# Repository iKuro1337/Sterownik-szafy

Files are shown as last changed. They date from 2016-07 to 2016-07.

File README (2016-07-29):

Sterownik oświetlenia w szafie oraz przejścia obok szafy

BOM płytka bazowa:
8x rezystor 10k
8x rezystor 60
8x IRLZ44N
8x złącza ARK 2pin
nx Listwy goldpin

BOM płytka sterująca Atmega32:
1x Atmega32
2x Zworka
1x Przycisk monostabilny
1x złącze ARK 2pin
4x kondensator 100n
1x rezystor 10k
1x rezystor pod diode (ok 200)
nx listwy goldpin

BOM obudowa:
3x JACK stereo (2 mogą być MONO)
1x wyświetlacz 4x20 z przetwornikiem i2c
1x czujnik ruchu PIR 5V HC-SR501
WIP czujnik oświetlenia.

Błędy (v1)
1) Odwrócone piny zasilające płytkę bazową 5V i 12V - jest 12V po lewej, 5V po prawej, ma być 5V po lewej, 12 po prawej (płytka Atmega32)
2) Za duży odstęp między pinami 12V,5V i GND wyprowadzonymi na płytce bazowej (płytka bazowa)
3) Za wąskie ścieżki zasilania - należy je pogrubić (wszystko)
4) Pady z przycisku stykają się z ramką płytki (płytka Atmega32)
5) Brak złącza na zasilanie/zasilacz poza obudową (obudowa)
6) Źle podłączane zasilanie - osobna płytka nie ma miejsca do trwałego umiejscowienia.

Podłączenie:
- Wyświetlacz 4x20 podpiąć pod piny 22 i 23 Atmega 32 bezpośrednio. Zasilanie wziąć z wyprowadzeń
- Zworkę podświetlenia wyświetlacza zastąpić przyciskiem kołyskowym bądź innym, spełniającym funkcję włączania/wyłączania podświetlenia.
- Oświetlenie jest podłączane do kolejnych złącz ARK na dowolnej zasadzie.
- Podłączenie czujnika ruchu PIR tylko i wyłącznie na pin 1 - wpinany na pojedyncze gniazdo JACK
- Podłączenie czujników otwarcia/zamknięcia strony szafy podłączyć do pinów 2 i 3, drugą stronę złączyć z masą - wpinane na wybrane jedno z dwóch gniazd JACK
- Poszczególne gniazda mają następujące funkcje (od prawej góry, dołu, do lewej strony dołu)
  1) Światło zewnętrzne zapalające się zawsze jak jest ruch
  2) Światło wewnętrzne szafy, góra, zapalająca się kiedy którekolwiek z drzwi jest otwarte
  3) Światło wewnętrzne szafy, lewa strona, zapalająca się kiedy lewe drzwi są otwarte
  4) Światło wewnętrzne szafy, lewa strona, zapalająca się kiedy lewe drzwi są otwarte
  5) Światło wewnętrzne szafy, prawa strona, zapalająca się kiedy prawe drzwi są otwarte
  6) Światło wewnętrzne szafy, prawa strona, zapalająca się kiedy prawe drzwi są otwarte
  7) Światło wewnętrzne szafy, prawa strona, zapalająca się kiedy prawe drzwi są otwarte
  8) Światło wewnętrzne szafy, prawa strona, zapalająca się kiedy prawe drzwi są otwarte
- Płytkę zasilającą ustawiamy na 5V, przylutowujemy do niej 4 kable (po poprawce) bądź 6 kabli (przed korektą) skręconą parę czerwony/czarny podpinamy od strony zasilania płytki. Dodatkowy przewód od strony +12V podłączany jest po prawej stronie płytki bazowej. przewód czerwony podłączamy po prawej stronie trójki pinów zasilających. przewód czerwony ma być podpięty po lewej stronie płytki.

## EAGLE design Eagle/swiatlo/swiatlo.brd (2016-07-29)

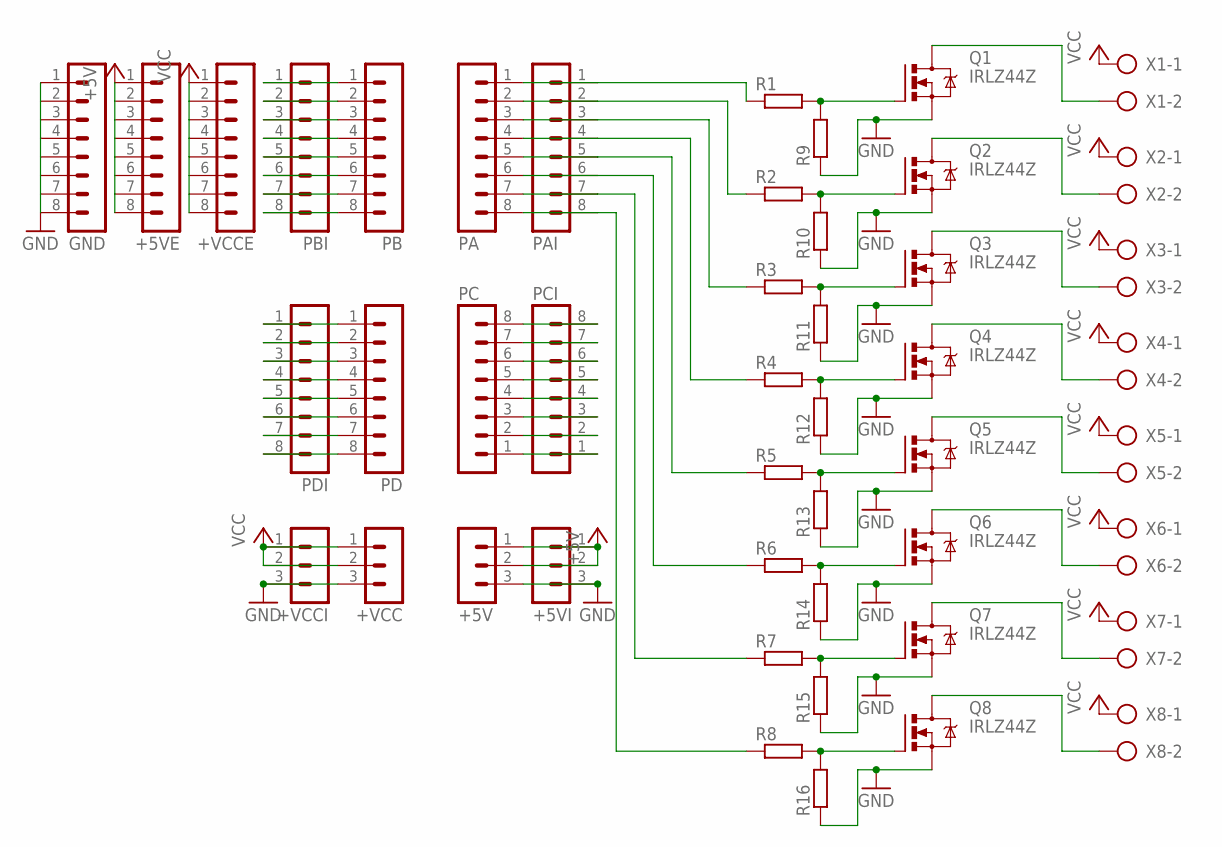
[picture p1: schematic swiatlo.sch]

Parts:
+5V, +5VI: MA03-1
+5VE: MA08-1
+VCC: MA03-1
+VCCE: MA08-1
+VCCI: MA03-1
GND: MA08-1
PA: MA08-1
PAI: MA08-1
PB: MA08-1
PBI: MA08-1
PC: MA08-1
PCI: MA08-1
PD: MA08-1
PDI: MA08-1
Q1, Q2, Q3, Q4, Q5, Q6, Q7, Q8: IRLZ44Z; TO220BH
R1, R2, R3, R4, R5, R6, R7, R8, R9, R10, R11, R12, R13, R14, R15, R16: R-EU_0204/7; 0204/7
X1, X2, X3, X4, X5, X6, X7, X8: AK300/2

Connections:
+5V: +5V.1, +5V.2, +5VE.1, +5VE.2, +5VE.3, +5VE.4, +5VE.5, +5VE.6, +5VE.7, +5VE.8, +5VI.1, +5VI.2
GND: +5V.3, +5VI.3, +VCC.3, +VCCI.3, GND.1, GND.2, GND.3, GND.4, GND.5, GND.6, GND.7, GND.8, Q1.S, Q2.S, Q3.S, Q4.S, Q5.S, Q6.S, Q7.S, Q8.S, R9.1, R10.1, R11.1, R12.1, R13.1, R14.1, R15.1, R16.1
unnamed: Q1.G, R1.2, R9.2
unnamed: Q2.G, R2.2, R10.2
unnamed: Q3.G, R3.2, R11.2
unnamed: Q4.G, R4.2, R12.2
unnamed: Q5.G, R5.2, R13.2
unnamed: Q6.G, R6.2, R14.2
unnamed: Q7.G, R7.2, R15.2
unnamed: Q8.G, R8.2, R16.2
unnamed: Q1.D, X1.2
unnamed: Q2.D, X2.2
unnamed: Q3.D, X3.2
unnamed: Q4.D, X4.2
unnamed: Q5.D, X5.2
unnamed: Q6.D, X6.2
unnamed: Q7.D, X7.2
unnamed: Q8.D, X8.2
unnamed: PC.8, PCI.8
unnamed: PC.7, PCI.7
unnamed: PC.6, PCI.6
unnamed: PC.5, PCI.5
unnamed: PC.4, PCI.4
unnamed: PC.3, PCI.3
unnamed: PC.2, PCI.2
unnamed: PC.1, PCI.1
unnamed: PA.1, PAI.1, R1.1
unnamed: PA.2, PAI.2, R2.1
unnamed: PA.3, PAI.3, R3.1
unnamed: PA.4, PAI.4, R4.1
unnamed: PA.5, PAI.5, R5.1
unnamed: PA.6, PAI.6, R6.1
unnamed: PA.7, PAI.7, R7.1
unnamed: PA.8, PAI.8, R8.1
unnamed: PD.8, PDI.8
unnamed: PD.7, PDI.7
unnamed: PD.6, PDI.6
unnamed: PD.5, PDI.5
unnamed: PD.4, PDI.4
unnamed: PD.3, PDI.3
unnamed: PD.2, PDI.2
unnamed: PD.1, PDI.1
unnamed: PB.8, PBI.8
unnamed: PB.7, PBI.7
unnamed: PB.6, PBI.6
unnamed: PB.5, PBI.5
unnamed: PB.4, PBI.4
unnamed: PB.3, PBI.3
unnamed: PB.2, PBI.2
unnamed: PB.1, PBI.1
VCC: +VCC.1, +VCC.2, +VCCE.1, +VCCE.2, +VCCE.3, +VCCE.4, +VCCE.5, +VCCE.6, +VCCE.7, +VCCE.8, +VCCI.1, +VCCI.2, X1.1, X2.1, X3.1, X4.1, X5.1, X6.1, X7.1, X8.1

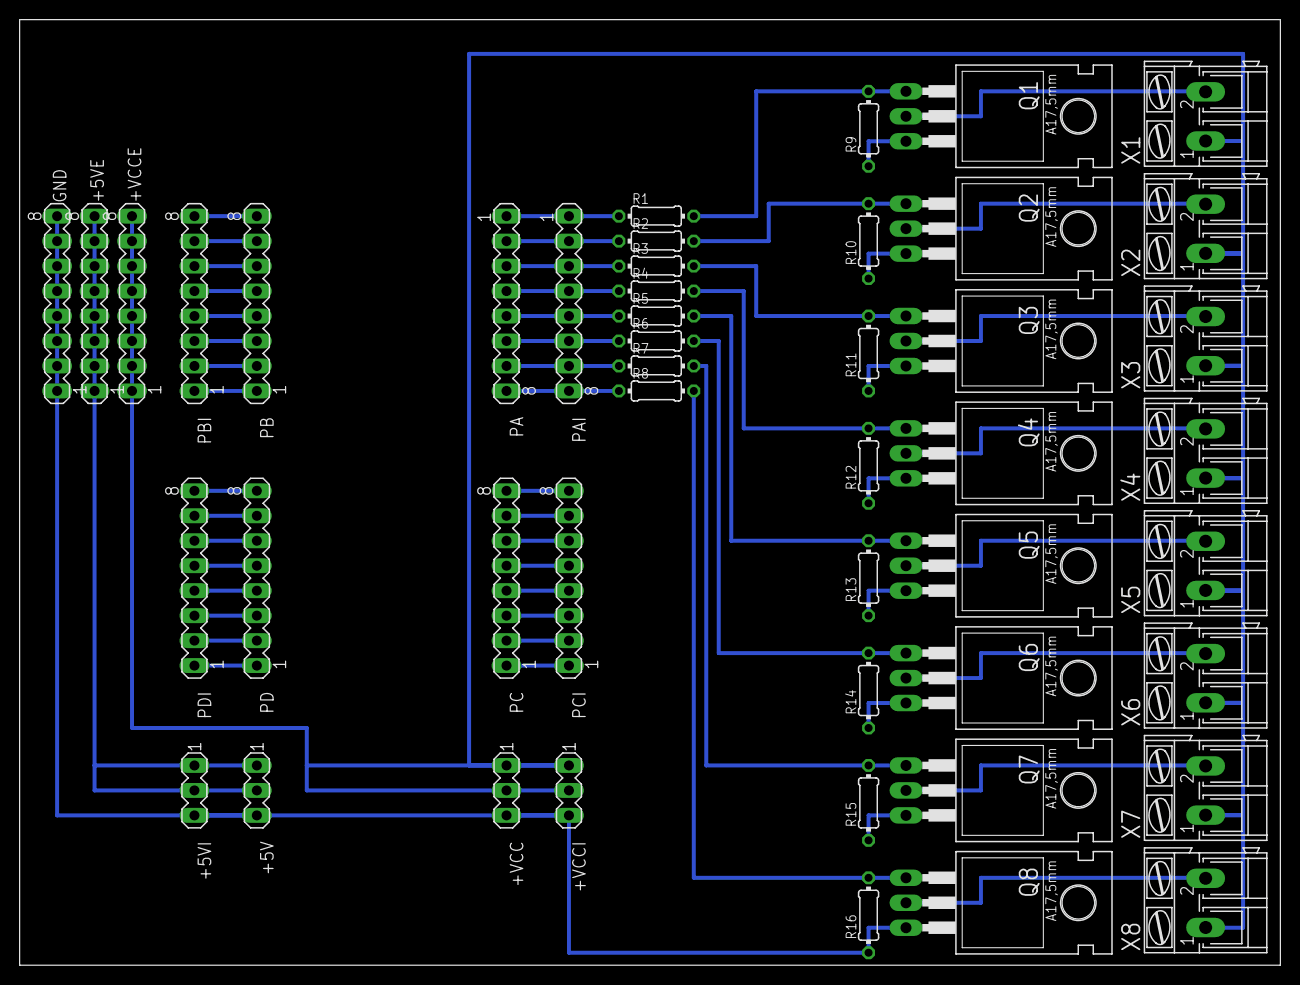
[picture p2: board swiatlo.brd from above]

Board: 2 copper layers, 128.2 x 96.2 mm, 47 parts (0 on the bottom side), 51 nets.

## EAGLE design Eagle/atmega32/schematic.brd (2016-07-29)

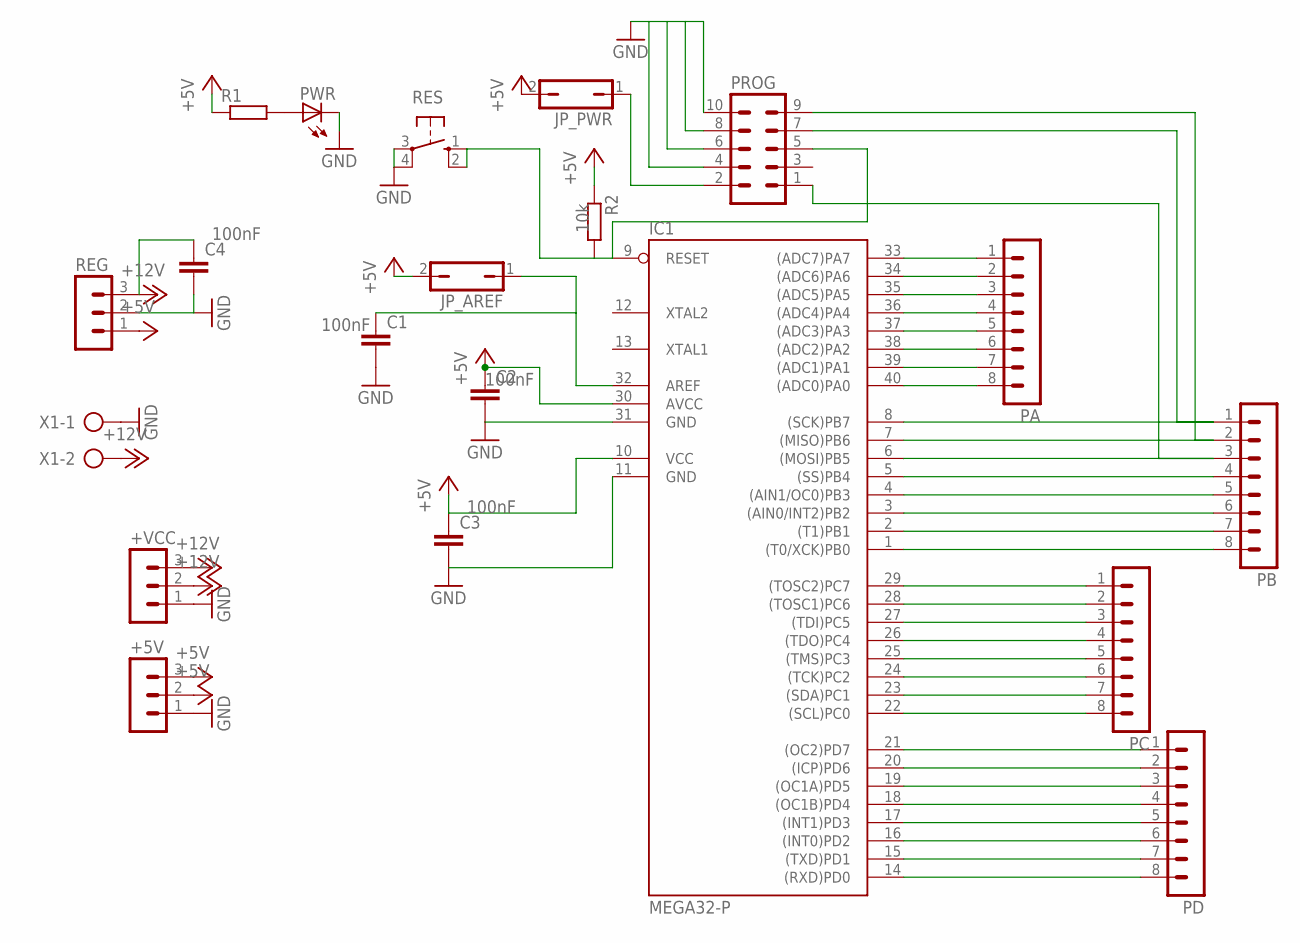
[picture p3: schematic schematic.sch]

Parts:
+5V: MA03-1
+VCC: MA03-1
C1, C2, C3, C4: C2,5-3; C2.5-3
IC1: MEGA32-P; DIL40
JP_AREF: JP1Q; JP1
JP_PWR: JP1Q; JP1
PA: MA08-1
PB: MA08-1
PC: MA08-1
PD: MA08-1
PROG: MA05-2
PWR: LED_E; LED_1206
R1, R2: RR1206; R1206
REG: MA03-1
RES: 10-XX; B3F-10XX
X1: AK300/2

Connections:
+5V: +5V.2, +5V.3, C2.1, C3.1, IC1.10 (VCC), IC1.30 (AVCC), JP_AREF.2, JP_PWR.2, R1.1, R2.1, REG.1
+12V: +VCC.2, +VCC.3, C4.1, REG.3, X1.2
GND: +5V.1, +VCC.1, C1.2, C2.2, C3.2, C4.2, IC1.11 (GND), IC1.31 (GND), PROG.4, PROG.6, PROG.8, PROG.10, PWR.C, REG.2, RES.3, RES.4 (P1), X1.1
unnamed: IC1.21 ((OC2)PD7), PD.1
unnamed: IC1.20 ((ICP)PD6), PD.2
unnamed: IC1.19 ((OC1A)PD5), PD.3
unnamed: IC1.18 ((OC1B)PD4), PD.4
unnamed: IC1.17 ((INT1)PD3), PD.5
unnamed: IC1.16 ((INT0)PD2), PD.6
unnamed: IC1.15 ((TXD)PD1), PD.7
unnamed: IC1.14 ((RXD)PD0), PD.8
unnamed: IC1.29 ((TOSC2)PC7), PC.1
unnamed: IC1.28 ((TOSC1)PC6), PC.2
unnamed: IC1.27 ((TDI)PC5), PC.3
unnamed: IC1.26 ((TDO)PC4), PC.4
unnamed: IC1.25 ((TMS)PC3), PC.5
unnamed: IC1.24 ((TCK)PC2), PC.6
unnamed: IC1.23 ((SDA)PC1), PC.7
unnamed: IC1.22 ((SCL)PC0), PC.8
unnamed: IC1.8 ((SCK)PB7), PB.1, PROG.7
unnamed: IC1.7 ((MISO)PB6), PB.2, PROG.9
unnamed: IC1.6 ((MOSI)PB5), PB.3, PROG.1
unnamed: IC1.5 ((SS)PB4), PB.4
unnamed: IC1.4 ((AIN1/OC0)PB3), PB.5
unnamed: IC1.3 ((AIN0/INT2)PB2), PB.6
unnamed: IC1.2 ((T1)PB1), PB.7
unnamed: IC1.1 ((T0/XCK)PB0), PB.8
unnamed: IC1.33 ((ADC7)PA7), PA.1
unnamed: IC1.34 ((ADC6)PA6), PA.2
unnamed: IC1.35 ((ADC5)PA5), PA.3
unnamed: IC1.36 ((ADC4)PA4), PA.4
unnamed: IC1.37 ((ADC3)PA3), PA.5
unnamed: IC1.38 ((ADC2)PA2), PA.6
unnamed: IC1.39 ((ADC1)PA1), PA.7
unnamed: IC1.40 ((ADC0)PA0), PA.8
unnamed: IC1.9 (RESET), PROG.5, R2.2, RES.1 (S), RES.2 (S1)
unnamed: C1.1, IC1.32 (AREF), JP_AREF.1
unnamed: JP_PWR.1, PROG.2
unnamed: PWR.A, R1.2

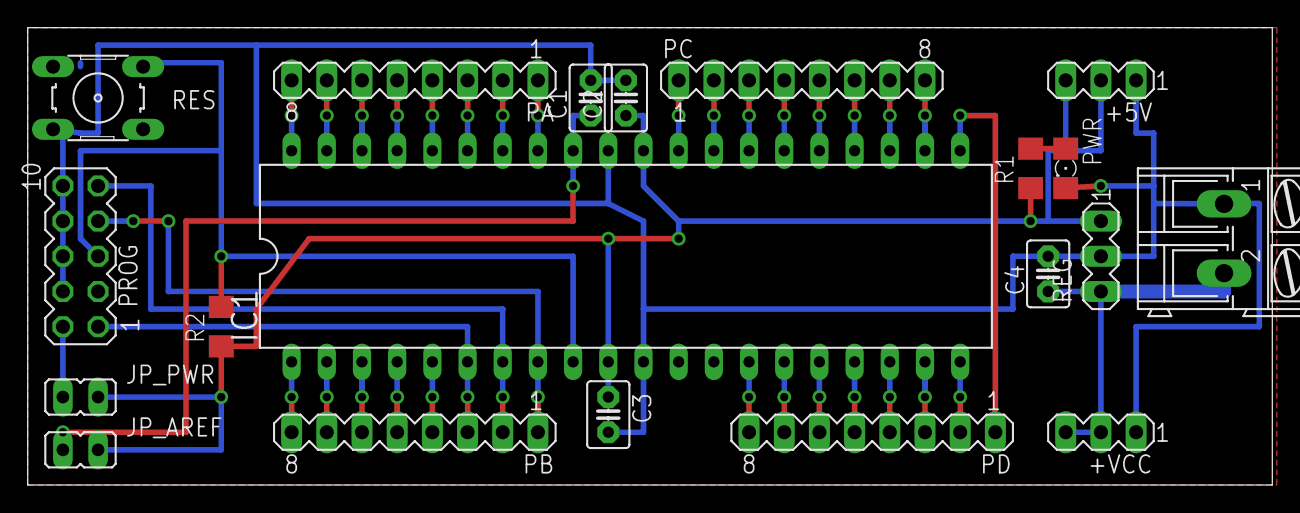
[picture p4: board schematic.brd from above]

Board: 2 copper layers, 89.8 x 33.0 mm, 20 parts (0 on the bottom side), 39 nets.

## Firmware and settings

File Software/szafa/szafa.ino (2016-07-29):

#include <BH1750.h>
#include <Wire.h>
#include <LiquidCrystal_I2C.h>

LiquidCrystal_I2C lcd(0x27, 20,4);  // Ustawienie adresu ukladu na 0x27
//BH1750 czujnikSwiatla;

#define PIRinput 0b00000001 //0
#define czujnikLewy 0b00000010 //1
#define czujnikPrawy 0b00000100 //2
#define prz1 0b00001000 //3
#define prz2 0b00010000 //4
#define prz3 0b00100000 //5
#define prz4 0b01000000 //6
#define debug_on 0b10000000 //7

#define szafaZewnatrz 0b00000001 //31
#define szafaGora 0b00000010 //30
#define szafaPolka1 0b00000100 //29
#define szafaPolka2 0b00001000 //28
#define szafaPolka3 0b00010000 //27
#define szafaPolka4 0b00100000 //26
#define szafaPolka5 0b01000000 //25
#define szafaPolka6 0b10000000 //24

void setup() {
  //BH1750
  //czujnikSwiatla.configure(BH1750_CONTINUOUS_LOW_RES_MODE);

  //LCD
  lcd.init();     // Inicjalizacja LCD 4x20
  lcd.backlight();
  lcd.setCursor(0,0);
  lcd.print("Program: Oswietlenie");
  lcd.setCursor(0,1);
  lcd.print("szafy 2.0");
  delay(500);

  //PINY - INPUT
  //  pinMode(PIRinput, INPUT_PULLUP);
  //  pinMode(czujnikLewy, INPUT_PULLUP);
  //  pinMode(czujnikPrawy, INPUT_PULLUP);
  DDRB |= 0b00000000;
  PORTB |= 0b00000110;

  //PINY - OUTPUT
  //  pinMode(szafaZewnatrz, OUTPUT);
  //  pinMode(szafaGora, OUTPUT);
  //  pinMode(szafaPolka1, OUTPUT);
  //  pinMode(szafaPolka2, OUTPUT);
  //  pinMode(szafaPolka3, OUTPUT);
  //  pinMode(szafaPolka4, OUTPUT);
  //  pinMode(szafaPolka5, OUTPUT);
  //  pinMode(szafaPolka6, OUTPUT);
  DDRA |= 0b11111111;
  PORTA |= 0b00000000;


  for (int i = 0; i < 8; i++) {
    lcd.setCursor(i+6,2);
    lcd.print("*");
    PORTA = (0b00000001 << i);
    delay(1000);
  }
  lcd.clear();
  lcd.setCursor(0,0);

}

void diagnostykaLCD(uint16_t lux_in, bool pir_in, bool czl_in, bool czp_in, bool szZ, bool szG, bool sz1, bool sz2, bool sz3, bool sz4, bool sz5, bool sz6) {
  char buffer[20];

  //lcd.clear();
  //stany wejsc na wyswietlacz
  sprintf(buffer, "PIR %01d CZL %01d CZP %01d   ", pir_in, czl_in, czp_in);
  lcd.setCursor(0,0);
  lcd.print(buffer);

  //stany wyjsc na wyswietlacz
  sprintf(buffer, "SZ %01d SG %01d P1 %01d P2 %01d ", szZ, szG, sz1, sz2);
  lcd.setCursor(0,1);
  lcd.print(buffer);
  sprintf(buffer, "P3 %01d P4 %01d P5 %01d P6 %01d ", sz3, sz4, sz5, sz6);
  lcd.setCursor(0,2);
  lcd.print(buffer);

  //czujnik oswietlenia
  sprintf(buffer, "LUX %05d  ", lux_in);
  lcd.setCursor(0,3);
  lcd.print(buffer);
}

void loop() {
  //********************************************************************************************************************************************************************************
  //DEFINICJE
  //********************************************************************************************************************************************************************************

  byte WEJSCIA = PINB;
  byte WYJSCIA_st = PINA;
  byte WYJSCIA_out = 0b00000000;

  //********************************************************************************************************************************************************************************
  //SPRAWDZANIE STANOW
  //********************************************************************************************************************************************************************************

  //WEJSCIA
  uint16_t lux_st/*=czujnikSwiatla.readLightLevel()*/;
  bool PIR_st = (WEJSCIA & PIRinput); //digitalRead(PIRinput);
  bool CZL_st = (WEJSCIA & czujnikLewy); //digitalRead(czujnikLewy);
  bool CZP_st = (WEJSCIA & czujnikPrawy); //digitalRead(czujnikPrawy);

  //WYJSCIA
  bool SZZ_st = (WYJSCIA_st & szafaZewnatrz); //digitalRead(szafaZewnatrz);
  bool SZG_st = (WYJSCIA_st & szafaGora); //digitalRead(szafaGora);
  bool SZ1_st = (WYJSCIA_st & szafaPolka1); //digitalRead(szafaPolka1);
  bool SZ2_st = (WYJSCIA_st & szafaPolka2); //digitalRead(szafaPolka2);
  bool SZ3_st = (WYJSCIA_st & szafaPolka3); //digitalRead(szafaPolka3);
  bool SZ4_st = (WYJSCIA_st & szafaPolka4); //digitalRead(szafaPolka4);
  bool SZ5_st = (WYJSCIA_st & szafaPolka5); //digitalRead(szafaPolka5);
  bool SZ6_st = (WYJSCIA_st & szafaPolka6); //digitalRead(szafaPolka6);

  //********************************************************************************************************************************************************************************
  //PROGRAM
  //********************************************************************************************************************************************************************************

  //Jezeli wykryto ruch:
  WYJSCIA_out |= PIR_st ? szafaZewnatrz : 0b00000000;
  WYJSCIA_out |= (PIR_st & (CZL_st | CZP_st)) ? szafaGora : 0b00000000;
  WYJSCIA_out |= (PIR_st & CZL_st) ? szafaPolka1 + szafaPolka2 : 0b00000000;
  WYJSCIA_out |= (PIR_st & CZP_st) ? szafaPolka3 + szafaPolka4 + szafaPolka5 + szafaPolka6 : 0b00000000;
  //WYJSCIA_out |= (PIR_st & (CZL_st | CZP_st)) ? (0b11111111) : (0b00000000);
  //PORTA ^= szafaPolka1; //digitalWrite(szafaPolka3,!digitalRead(szafaPolka3));


  //********************************************************************************************************************************************************************************
  //WYSTEROWANIE WYJSC
  //********************************************************************************************************************************************************************************

  PORTA = WYJSCIA_out;
  delay(200);

  //diagnostyka stanów na podpiętym LCD
  //f (WEJSCIA & debug_on){
  diagnostykaLCD(lux_st, PIR_st, CZL_st, CZP_st, SZZ_st, SZG_st, SZ1_st, SZ2_st, SZ3_st, SZ4_st, SZ5_st, SZ6_st);
  //}
}
